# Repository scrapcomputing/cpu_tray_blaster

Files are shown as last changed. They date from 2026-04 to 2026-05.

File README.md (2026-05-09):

# CPU Tray Blaster

A stackable, easy to print, 3D-printed CPU tray for many types of CPUs.

<p float="left">
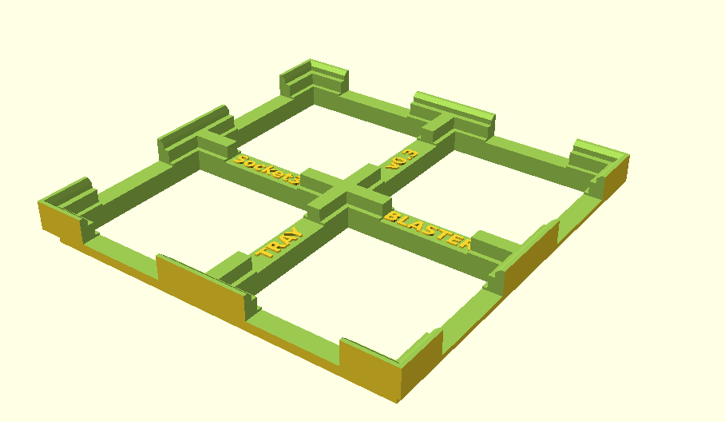
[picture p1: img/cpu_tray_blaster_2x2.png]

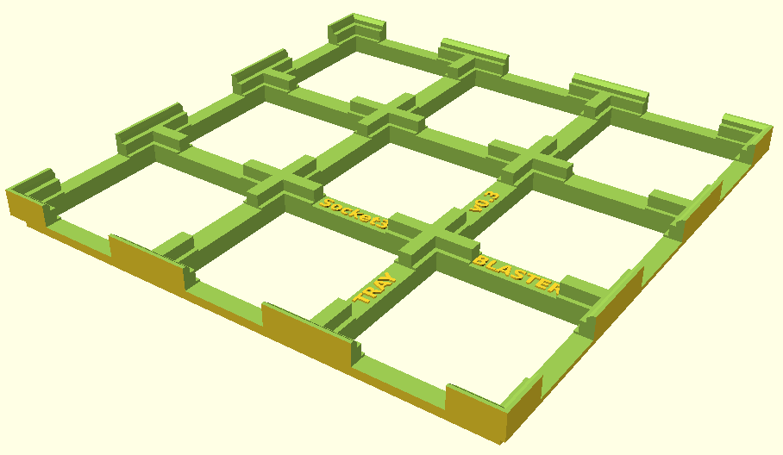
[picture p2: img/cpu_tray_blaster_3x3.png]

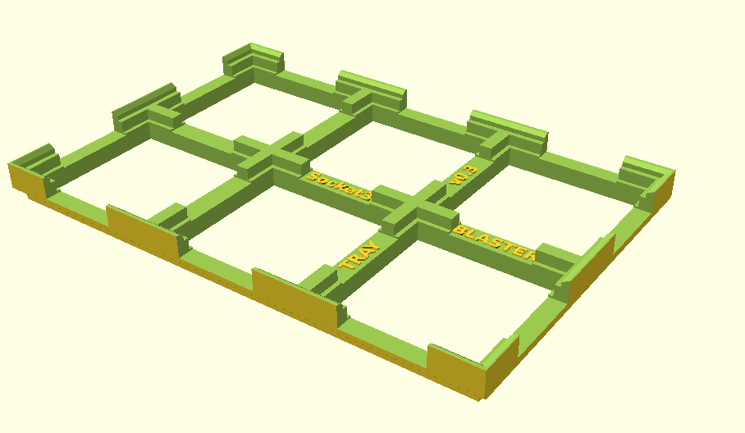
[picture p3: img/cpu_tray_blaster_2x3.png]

</p>

<p float="left">
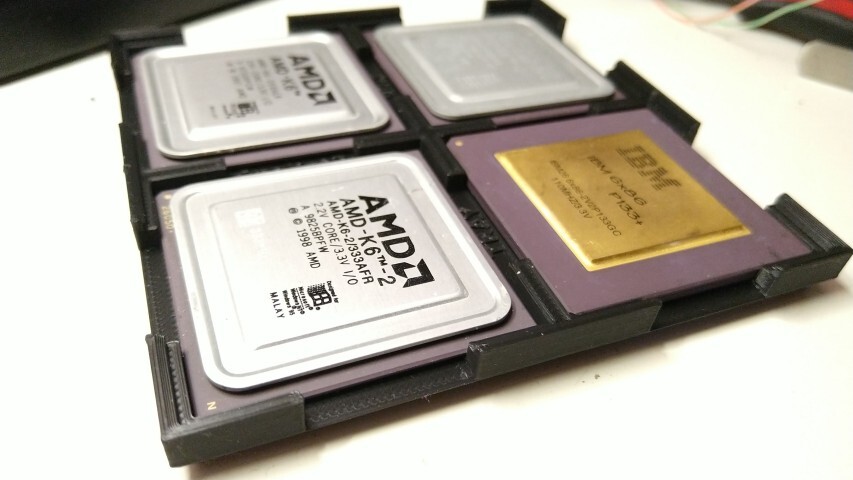
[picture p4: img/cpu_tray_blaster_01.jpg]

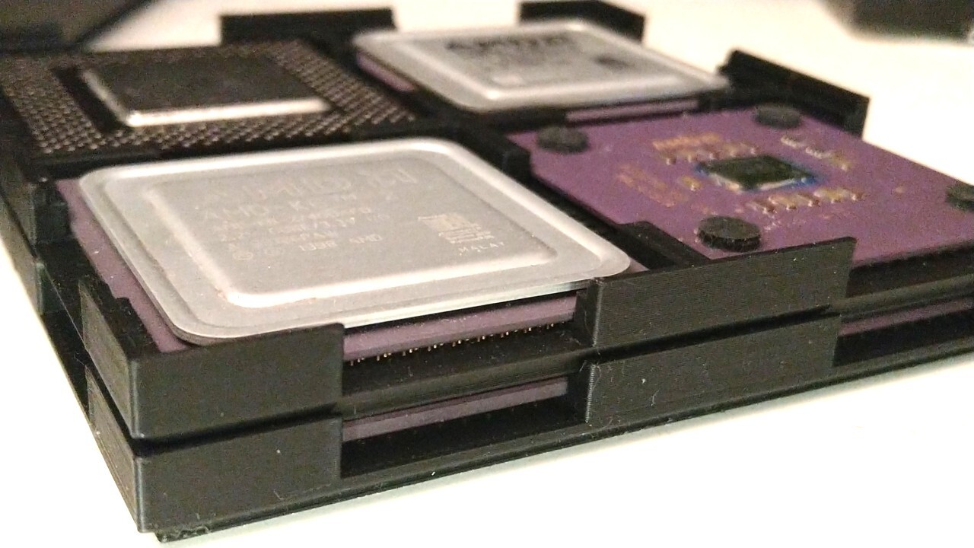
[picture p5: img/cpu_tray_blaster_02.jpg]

</p>

# Download STLs

You can [download](https://github.com/scrapcomputing/cpu_tray_blaster/releases) the zipped STL files for all sockets and several grid sizes in the releases.

# Video

- https://www.youtube.com/watch?v=UIG3XeRwU4c

# Features

- Stackable (only for same socket and grid size)
- Easy to place/remove CPUs
- Print with no supports and ready to use after print
- Structurally not too flimsy
- Kind on CPU pins as the pins are floating and not touching the tray
- Adjustable grid size from 1x1 to any NxM
- Large number of supported sockets (see below) and easy to add new ones
- CPUs can be placed in any orientation, no key.

# 3D-printing options

- No supports
- Prints fine on an Ender 3 style printer in standard quality
- Orientation: as shown in photos

# Disclaimer

This may not be a good CPU storage solution if you care about not having your CPUs get damaged from electrostatic discharge.
PLA, to the best of my knowledge, is not a safe material from the electrostatic sensitivity perspective.
So proceed at your own risk!

# Supported sockets

Compatibility is based on the CPU dimensions, not the pin count.
For example, Socket A CPUs fit in Socket 7 trays because the external dimensions of an Athlon Socket A CPU are identical on the X and Y axis, but Socket 7 CPUs can be taller, so Socket A trays won't necessarily fit some tall Cyrix 6x86.

| Name |  Description |
|---|---|
| socket386  | Ceramic 386 |
| socket387  | Ceramic 387 math co-processor (Cyrix 387DX)  |
| socket3 | All 486 CPUs, am5x86, Cyrix 5x86 |
| socket4 | Only the early Pentium 60/66 |
| socket7 | Pentium, K5, K6, Cyrix 6x86, K7, Pentium iii |
| socket370  | Pentium iii, Celeron |
| socketA | K7 Athlons, Durons |
| socket478  | Pentium IV Northwood+ |
| socketAM | Athlon 64 754, 939, AM1, AM2, AM3, AM4 |
| socketCore | 775, 1150, 1151 Core Duo,i3,15,i7 |
| socket1366 | Xeon, i7-9xx |
| socket2011 | Xeon and E-class Core i7s |
| socketG34  | Some Opteron versions |

# Build from source

## Easy

Open `cpu_tray_blaster.scad` in [https://openscad.org/](OpenScad), then export to stl.

## Bulk

Use `make` to generate one or more cpu tray stl files.

```
openscad=/path/to/openscad make                   # for a 2x2 stl files for all sockets
openscad=/path/to/openscad make -j 4              # same but with 4 jobs in parallel (faster)
openscad=/path/to/openscad make socket3_2x2.stl   # for a 2x2 socket3 stl file
openscad=/path/to/openscad make socket7_3x3.stl   # for a 3x3 socket7 stl file
openscad=/path/to/openscad grid=3x3 make          # for all 3x3 sockets
```

For a full set of supported sockets please refer to `params.json`.

# Change Log
- Rev 0.3: Initial public release.

# License
The project is GPLv2.

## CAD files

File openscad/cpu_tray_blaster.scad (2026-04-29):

// By Scrap Computing

// CPU measurements
//
//  (side view)
//
//  |------ cpu_x ----|
//      ___________     ___
//   __|___________|__   |  cpu_z
//  |_________________| _|_  ___
//     |||||||||||||         _|_ pin_z
//                  <->
//                  pin_border


// Usage:
// $ openscad -P socket3 -p params.json cpu_tray_blaster.scad -o socket3.stl -D grid_x=2 -D grid_y=2

// Socket 3 (486)
cpu_x = 44.5;
cpu_y = 44.5;
cpu_z = 4.0;
pin_z = 4.2;
pin_border = 1.26;
txt = "Socket3";

// This will create a <grid_x> X <grid_y> tray.
grid_x = 2;
grid_y = 2;

// This helps make the tray less flimsy, especially for large grids. If you are OK with a flimsy frame for CPUs with pads then you can set this to 0.
min_pin_z = (grid_x <= 2 && grid_y <= 2) ? 2.2 : 3.2;

// This limit is mainly for LGA CPUS that have pads all the way to the edge. We need a pin border large enough to hold the CPU on the tray.
min_pin_border = 1.2;

// Text.
text_height = 0.5;
text_txt1 = "TRAY";
text_sz = 3.6;
text_txt2 = "BLASTER";
text_version = "v0.3";
text_font = "DejaVu Sans:style=Bold";


// We need a minimum pin height to make sure the base is thick enough.
pin_z_adj = max(pin_z, min_pin_z);
// Otherwise the CPU may fall through the tray.
pin_border_adj = max(pin_border, min_pin_border);

wiggle_room = 0.6; // We set the CPU dimensions this much higher to allow for printing errors
cpu_size_x = cpu_x + wiggle_room;
cpu_size_y = cpu_y + wiggle_room;
cpu_pin_height = pin_z_adj + wiggle_room;
cpu_total_height = pin_z_adj + cpu_z;

// The CPU Lip is the gap that allows you to to remove
// the CPUs from the tray more easily.
// NOTE: These don't need to be changed by the user.
cpu_lip_sz = 24;
cpu_lip_depth = 10;
cpu_lip_thickness = cpu_z + 10;
cpu_lip_upnder_pins_offset = 0.6; // The smaller it is the thicker the grid but harder to remove the CPUs
cpu_lip_z = cpu_pin_height - cpu_lip_upnder_pins_offset;
cpu_distance_from_floor = 1.0;

// The tray
tray_cpu_gap = 3.8; // Gap between the CPUs. The smaller it is the harder it is to place your finger and pick up the CPU.
// The tray's stack lip allows you to stack one tray to the other.
tray_stack_lip_angle = 45;
tray_stack_lip_width = 2.2;
// Helps stacked trays stay in place.
tray_stack_vertical_step = 1.4;
// Reduce the top edge, make it flat.
tray_stack_top_no_edge = 1.6;
tray_stack_lip_top_thickness = 1.8 + tray_stack_vertical_step;
tray_stack_wiggle = 0.6; // We make the top lip larger than the bottom
tray_stack_lip_bot_thickness = tray_stack_lip_top_thickness + 2 * tray_stack_wiggle / tan(tray_stack_lip_angle);
tray_grid_height = cpu_total_height + + cpu_distance_from_floor + tray_stack_lip_top_thickness;

// The gap for the indents that help you pick up the CPU from the tray.
module cpu_lip_impl(cpu_size) {
    translate([-cpu_lip_sz/2, -cpu_size/2 - cpu_lip_depth/2, cpu_lip_z])
        cube([cpu_lip_sz, cpu_lip_depth, cpu_lip_thickness]);
    translate([-cpu_lip_sz/2, +cpu_size/2 - cpu_lip_depth/2, cpu_lip_z])
        cube([cpu_lip_sz, cpu_lip_depth, cpu_lip_thickness]);
}
module cpu_lip() {
    cpu_lip_impl(cpu_size_y);
    rotate([0, 0, 90])cpu_lip_impl(cpu_size_x);   
}

// The CPU with the indent
module cpu() {
        union() {
            xtra_z = cpu_distance_from_floor; // Additional height that makes sure we have a gap under the pins
            translate([-cpu_size_x/2 + pin_border_adj, -cpu_size_y/2 + pin_border_adj, - xtra_z])
                cube([cpu_size_x - 2 * pin_border_adj, cpu_size_y - 2 * pin_border_adj, cpu_pin_height + xtra_z]);
            translate([-cpu_size_x/2, -cpu_size_y/2, cpu_pin_height])
                 cube([cpu_size_x, cpu_size_y, cpu_z]);
            cpu_lip();
        }
}

// The stacking lip at the top of the tray
module tray_stack_cube_top(tray_sz_x, tray_sz_y, height) {
  r = tray_sz_x * cos(45); // cos(45) is because we are using a cylinder to draw a pyramid
  r1 = r;
  r2 = r1 + height * tan(tray_stack_lip_angle);

  // Scale to support non-square cpus
  scale([(tray_sz_x - 2 * tray_stack_lip_width)/tray_sz_x, (tray_sz_y - 2 * tray_stack_lip_width)/tray_sz_x, 1.0])
    rotate([0, 0, 45]) {
      translate([0, 0, tray_stack_vertical_step])cylinder(h = height - tray_stack_vertical_step, r1 = r1, r2 = r2, $fn = 4);
      cylinder(h=tray_stack_vertical_step, r = r1, $fn = 4);
    }
}

// The inverse of the top lip for the bottom of the tray
// that locks with the top lip.
module tray_stack_cube_bot(tray_sz_x, tray_sz_y) {
   difference() {
      cube_height = tray_stack_lip_bot_thickness;
      translate([0, 0, cube_height/2])
         cube([tray_sz_x + 0.1, tray_sz_y + 0.1, cube_height], center = true); // + 0.1 makes the "ghost" vertical planes disappear
         tray_stack_cube_top(tray_sz_x - tray_stack_wiggle, tray_sz_y - tray_stack_wiggle, cube_height);
    }
}

// Draws text at (x,y)
module text_stamp(x, y, txt, rot = 0) {
    z = cpu_lip_z + cpu_distance_from_floor;
    translate([x, y, z])
      rotate([0, 0, rot])
       linear_extrude(text_height)
          text(txt, text_sz, text_font, halign = "center", valign = "baseline");
}

module tray(NX, NY) {
    tray_sz_x = NX * cpu_size_x + (NX + 1) * tray_cpu_gap;
    tray_sz_y = NY * cpu_size_y + (NY + 1) * tray_cpu_gap;

    difference() {
        cube([tray_sz_x, tray_sz_y, tray_grid_height]);

        union() {
            translate([tray_sz_x/2, tray_sz_y/2, 0])
               tray_stack_cube_bot(tray_sz_x, tray_sz_y);
               translate([tray_sz_x/2, tray_sz_y/2, tray_grid_height - tray_stack_lip_top_thickness])
                  union() {
                      // Trim the top to avoid pointy edges
                      translate([0, 0, tray_stack_lip_top_thickness + 0])cube([tray_sz_x + 0.1, tray_sz_y + 0.1, tray_stack_top_no_edge], center = true); // + 0.1 removes "ghost" vertical planes

                      tray_stack_cube_top(tray_sz_x, tray_sz_y, tray_stack_lip_top_thickness);
                  }

               
               for (x = [1:1:NX]) {
                  for (y = [1:1:NY]) {
                     offset_x = cpu_size_x * (x-1)+ tray_cpu_gap * x;
                     offset_y = cpu_size_y * (y-1) + tray_cpu_gap * y;
                     translate([offset_x, offset_y, cpu_distance_from_floor]) 
                      translate([cpu_size_x/2, cpu_size_y/2, 0])cpu();
               }
           }
        }
    }
    
    if (NX >= 2 && NY >= 2) {
      x1 = tray_cpu_gap + cpu_size_x / 2;
      y1 = tray_cpu_gap + cpu_size_y + (tray_cpu_gap - text_sz) / 2;
      text_stamp(x1, y1, text_txt1);

      x2 = tray_cpu_gap + cpu_size_x + tray_cpu_gap + cpu_size_x/2;
      text_stamp(x2 , y1, text_version);
    
      x3 = tray_cpu_gap + cpu_size_x + (tray_cpu_gap - text_sz)/2;
      y3 = tray_cpu_gap + cpu_size_y/2;
      text_stamp(x3, y3, text_txt2, -90); 
      
      y4 = tray_cpu_gap + cpu_size_y + tray_cpu_gap + cpu_size_y/2;
      text_stamp(x3, y4, txt, -90);
    }   
}

tray(grid_x, grid_y);
